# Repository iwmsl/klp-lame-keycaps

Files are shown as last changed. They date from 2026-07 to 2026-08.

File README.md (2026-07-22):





# KLP Lamé — Kailh Choc & MX Keycaps

Sculpted and curved keycaps for Kailh Choc and MX switches. Here is a project structure:

| Folder | Description |
| :--- | :--- |
| **Assets** | Various images and actual photos of keycaps |
| **Blender** | Blender files for preview image render |
| **Fusion 360** | Source files for [Autodesk Fusion 360](https://www.autodesk.com/products/fusion-360/overview) |
| **OpenSCAD** | Parametric [Angular](./OpenSCAD/README.md) remix — flat-sided, lower-profile variant |
| **Production** | Combined STL 3D models suitable for 3D-Printing services (like [JLC3DP](https://jlc3dp.com))  |
| **STEP** | 3D models in STEP format for any CAD or Slicer software |
| **STL** | 3D models in STL format for any CAD or Slicer software |

## Angular remix (OpenSCAD)

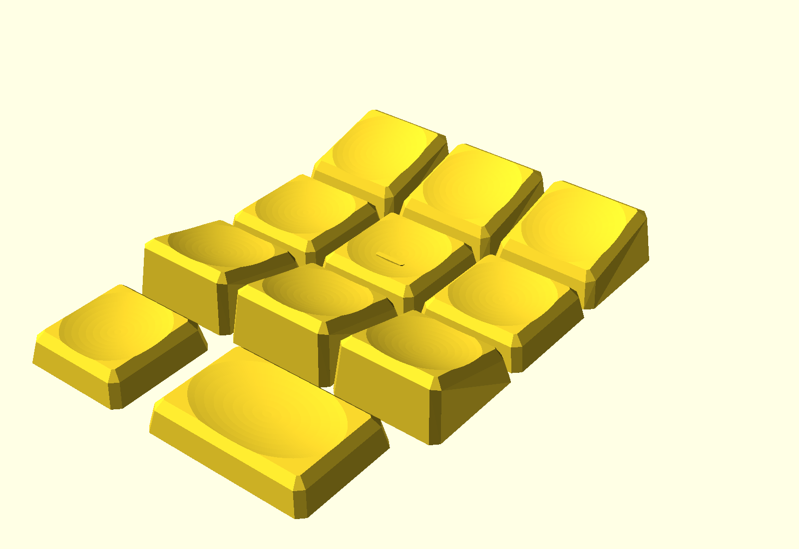
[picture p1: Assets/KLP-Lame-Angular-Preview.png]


There is also an angular, slightly lower-profile remix of the Lamé profile
with flat trapezoid sides, keeping the signature sloped & dished top. It is
fully parametric (OpenSCAD) and FDM-friendly (e.g. Bambu Lab A1 mini).
See [OpenSCAD/README.md](./OpenSCAD/README.md) for parameters, prebuilt STLs
and printing notes.

> `STEP` and `STL` folders contain all combinations of Choc/MX Stem + Choc/MX Size.
>
> There is also `90 deg Rotated` variants for Choc Stem.

There are currently 7 variants of 1U keycaps:
| Variant | Description |
| :--- | :--- |
| **Normal** | Just a flat keycap profile with a small recess, that is soothing for fingers |
| **Normal Tilted** | Same as Normal, but top profile has a 15° tilt and 0.5mm upward height compensation |
| **Normal Homing** | Has three little bumps that is useful to determine home positions |
| **Thumb** | Same as Normal, but top profile has a cut along down side |
| **Saddle** | Same as Thumb, but top profile has two symmetrical cuts |
| **Saddle Tilted** | Tilted version of Saddle. Same 15° and height compensation |
| **Saddle Homing** | Has three little bumps that is useful to determine home positions |

And also 5 variants of 1.5U keycaps:
| Variant | Description |
| :--- | :--- |
| **Normal** | Just a flat keycap profile with a small recess, that is soothing for fingers |
| **Thumb H**  | 1.5U variant of Thumb. Horizontal |
| **Thumb V**  | 1.5U variant of Thumb. Vertical (stem is rotated) |
| **Saddle H** | 1.5U variant of Saddle. Horizontal |
| **Saddle V** | 1.5U variant of Saddle. Vertical (stem is rotated) |

## What keycaps do I need for my keyboard?

First, you should choose Choc/MX stem (depends of your switches)<br>
Second, choose Choc/MX size that is suitable for your keyboard.<br>
Then, pick what keycap variants you want for your columns/rows/thumbs. It depends entirely of your choice.

For corne-like keyboards with 36-keys I use:

| Amount | Kind | Purpose |
| -----: | :--- | :--- |
| 20 | Saddle Tilted | For top and bottom rows |
| 16 | Saddle | For home row + 6 for thumbs |

or

| Amount | Kind | Purpose |
| -----: | :--- | :--- |
| 20 | Normal Tilted | For top and bottom rows |
| 10 | Normal | For home row |
| 6 | Thumb | For thumbs |

## How to print?

It is best to position the model more vertically to avoid tactile layer-to-layer bumps. Personally, I use 45° or 75° angle, but it's up to you.

`Production` folder contains files that you can use in any 3D-printing service like [JLC3DP](https://jlc3dp.com) or [PCBWay](https://www.pcbway.com/rapid-prototyping/3d-printing/). You can download them directly using links below:

### Normal

| File | Choc Stem + Choc Size | Choc Stem + MX Size | MX Stem + MX Size | MX Stem + Choc Size | Kinds |
| :--- | :--- | :--- | :--- | :--- | --- |
| Normal Part 1 | [Download][normal-part-1-choc] | [Download][normal-part-1-choc-mx] | [Download][normal-part-1-mx] | [Download][normal-part-1-mx-choc] | - 6 × Normal Tilted<br/>- 3 × Normal |
| Normal Part 2 | [Download][normal-part-2-choc] | [Download][normal-part-2-choc-mx] | [Download][normal-part-2-mx] | [Download][normal-part-2-mx-choc] | - 4 × Normal Tilted<br/>- 3 × Thumb<br/>- 1 × Normal Homing<br/>- 1 × Normal |
| Normal Part 3 | [Download][normal-part-3-choc] | [Download][normal-part-3-choc-mx] | [Download][normal-part-3-mx] | [Download][normal-part-3-mx-choc] | - 9 × Normal Tilted |

### Saddle

| File | Choc Stem + Choc Size | Choc Stem + MX Size | MX Stem + MX Size | MX Stem + Choc Size | Kinds |
| :--- | :--- | :--- | :--- | :--- | --- |
| Saddle Part 1 | [Download][saddle-part-1-choc] | [Download][saddle-part-1-choc-mx] | [Download][saddle-part-1-mx] | [Download][saddle-part-1-mx-choc] | - 6 × Saddle Tilted<br/>- 3 × Saddle |
| Saddle Part 2 | [Download][saddle-part-2-choc] | [Download][saddle-part-2-choc-mx] | [Download][saddle-part-2-mx] | [Download][saddle-part-2-mx-choc] | - 4 × Saddle Tilted<br/>- 4 × Saddle<br/>- 1 × Saddle Homing |
| Saddle Part 3 | [Download][saddle-part-3-choc] | [Download][saddle-part-3-choc-mx] | [Download][saddle-part-3-mx] | [Download][saddle-part-3-mx-choc] | - 9 × Saddle Tilted |

### Thumbs

| File | Choc Stem + Choc Size | Choc Stem + MX Size | MX Stem + MX Size | MX Stem + Choc Size | Kinds |
| :--- | :--- | :--- | :--- | :--- | --- |
| Thumbs | [Download][thumbs-part-1-choc] | [Download][thumbs-part-1-choc-mx] | [Download][thumbs-part-1-mx] | [Download][thumbs-part-1-mx-choc] | - 9 × Thumb |

[normal-part-1-choc]: ./Production/Choc%20Stem%20%2B%20Choc%20Size/Choc_Stem_Choc_Size_Normal_Part_1.zip
[normal-part-2-choc]: ./Production/Choc%20Stem%20%2B%20Choc%20Size/Choc_Stem_Choc_Size_Normal_Part_2.zip
[normal-part-3-choc]: ./Production/Choc%20Stem%20%2B%20Choc%20Size/Choc_Stem_Choc_Size_Normal_Part_3.zip

[normal-part-1-choc-mx]: ./Production/Choc%20Stem%20%2B%20MX%20Size/Choc_Stem_MX_Size_Normal_Part_1.zip
[normal-part-2-choc-mx]: ./Production/Choc%20Stem%20%2B%20MX%20Size/Choc_Stem_MX_Size_Normal_Part_2.zip
[normal-part-3-choc-mx]: ./Production/Choc%20Stem%20%2B%20MX%20Size/Choc_Stem_MX_Size_Normal_Part_3.zip

[normal-part-1-mx]: ./Production/MX%20Stem%20%2B%20MX%20Size/MX_Stem_MX_Size_Normal_Part_1.zip
[normal-part-2-mx]: ./Production/MX%20Stem%20%2B%20MX%20Size/MX_Stem_MX_Size_Normal_Part_2.zip
[normal-part-3-mx]: ./Production/MX%20Stem%20%2B%20MX%20Size/MX_Stem_MX_Size_Normal_Part_3.zip

[normal-part-1-mx-choc]: ./Production/MX%20Stem%20%2B%20Choc%20Size/MX_Stem_Choc_Size_Normal_Part_1.zip
[normal-part-2-mx-choc]: ./Production/MX%20Stem%20%2B%20Choc%20Size/MX_Stem_Choc_Size_Normal_Part_2.zip
[normal-part-3-mx-choc]: ./Production/MX%20Stem%20%2B%20Choc%20Size/MX_Stem_Choc_Size_Normal_Part_3.zip

[saddle-part-1-choc]: ./Production/Choc%20Stem%20%2B%20Choc%20Size/Choc_Stem_Choc_Size_Saddle_Part_1.zip
[saddle-part-2-choc]: ./Production/Choc%20Stem%20%2B%20Choc%20Size/Choc_Stem_Choc_Size_Saddle_Part_2.zip
[saddle-part-3-choc]: ./Production/Choc%20Stem%20%2B%20Choc%20Size/Choc_Stem_Choc_Size_Saddle_Part_3.zip

[saddle-part-1-choc-mx]: ./Production/Choc%20Stem%20%2B%20MX%20Size/Choc_Stem_MX_Size_Saddle_Part_1.zip
[saddle-part-2-choc-mx]: ./Production/Choc%20Stem%20%2B%20MX%20Size/Choc_Stem_MX_Size_Saddle_Part_2.zip
[saddle-part-3-choc-mx]: ./Production/Choc%20Stem%20%2B%20MX%20Size/Choc_Stem_MX_Size_Saddle_Part_3.zip

[saddle-part-1-mx]: ./Production/MX%20Stem%20%2B%20MX%20Size/MX_Stem_MX_Size_Saddle_Part_1.zip
[saddle-part-2-mx]: ./Production/MX%20Stem%20%2B%20MX%20Size/MX_Stem_MX_Size_Saddle_Part_2.zip
[saddle-part-3-mx]: ./Production/MX%20Stem%20%2B%20MX%20Size/MX_Stem_MX_Size_Saddle_Part_3.zip

[saddle-part-1-mx-choc]: ./Production/MX%20Stem%20%2B%20Choc%20Size/MX_Stem_Choc_Size_Saddle_Part_1.zip
[saddle-part-2-mx-choc]: ./Production/MX%20Stem%20%2B%20Choc%20Size/MX_Stem_Choc_Size_Saddle_Part_2.zip
[saddle-part-3-mx-choc]: ./Production/MX%20Stem%20%2B%20Choc%20Size/MX_Stem_Choc_Size_Saddle_Part_3.zip

[thumbs-part-1-choc]: ./Production/Choc%20Stem%20%2B%20Choc%20Size/Choc_Stem_Choc_Size_Thumbs.zip
[thumbs-part-1-choc-mx]: ./Production/Choc%20Stem%20%2B%20MX%20Size/Choc_Stem_MX_Size_Thumbs.zip
[thumbs-part-1-mx]: ./Production/MX%20Stem%20%2B%20MX%20Size/MX_Stem_MX_Size_Thumbs.zip
[thumbs-part-1-mx-choc]: ./Production/MX%20Stem%20%2B%20Choc%20Size/MX_Stem_Choc_Size_Thumbs.zip

## Can I use these models for a production and sale?

Yes. But you must leave a mention of this repository/author to end users.

## Can I modify, fork, post (or whatever) these models?

Yes. Rules are the same. Give a credit to the author.

## Changelog
v1.5u
- [Models] Well, 1.5U keycap sizes for both Choc/MX Stem + Choc/MX Size.

v1.4
- [Models] Updated Choc Stem to be compatible with silent choc switches.
- [Project] Added Choc_Stem + MX_Size 90° rotated variants (both STL and STEP).
- [Production] Increased surface area of connected parts to improve print stability.

v1.3
- [Models] Added mix and match variants for Choc/MX Stem + Choc/MX Size.
- [Project] Updated folder structure to accomodate mix and match variants.
- [Project] Removed Lychee (legacy) project files.

v1.2
- [Models] Added Choc version with 90° rotated stem.

v1.1

- [Models] Added chamfers along inner bottom line (1.2mm for Choc and 1.4mm for MX).
- [Project] Added separate Fusion project files.
- [Project] Updated Images & Photos.

> Now the models are also suitable for FDM 3D Printers. But I still recommend using SLA for better quality.

v1.0

- Initial Release.

## Images & Photos

### From various awesome people


By [u/unspecified-work](https://www.reddit.com/user/unspecified-work/) from [Reddit](https://www.reddit.com/r/ErgoMechKeyboards/comments/1oznwnv/splayed_sweep/)


By [u/socopopes](https://www.reddit.com/user/socopopes/) from [Reddit](https://www.reddit.com/r/ErgoMechKeyboards/comments/1dx9d7j/down_14_more_keys_only_34_more_to_go/)


By [u/bert_plasschaert](https://www.reddit.com/user/bert_plasschaert/) from [Reddit](https://www.reddit.com/r/ErgoMechKeyboards/comments/1dmirsg/totem_tenting_bottom_plate/)


By [proostas](https://t.me/proostas) from [Ergonaut Keyboards Ru](https://t.me/ergonautkb_ru)

### Original photos



> The keyboard is my side-project [Lapka](https://github.com/braindefender/lapka)




> The keyboard is [Cantor Remix](https://github.com/nilokr/cantor-remix)

## Contacts

@braindefender (preferably, [Telegram](t.me/braindefender), but also [GMail](mailto:braindefender@gmail.com) and [Reddit](https://www.reddit.com/user/braindefender/))

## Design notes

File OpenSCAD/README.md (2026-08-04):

# KLP Lamé Angular (OpenSCAD)



KLP Lamé の特徴である「中央がくぼみ四辺が持ち上がる皿状の天面(前後のロールオフ)」を
保ちつつ、側面を**フラットで角のはっきりした台形**にした **角ばった・低背リミックス** です。
天面は元と同じ球面ディッシュ、側面はフラット、稜線だけを軽く丸めた「ラウンデッドボックス」構成。
OpenSCAD 製のフルパラメトリックモデルなので、寸法・形状を自由に調整できます。

An angular, lower-profile remix of KLP Lamé. Flat, crisp trapezoid
sides (a "rounded box" with only the perimeter edges softened) carry
the same spherical dish as the original — concave scoop rising toward
all four edges, rolling off over the front/back walls. Fully parametric
OpenSCAD source. Stem and cavity dimensions are measured from the
original STLs, so switch fit is identical to the originals.

## 特徴 / Features

- **角ばった形状** — 側面はフラット、稜線のみ軽い丸め
- **詰めた間隔** — 19.05mm ピッチ向けに底面 18.5×18.5mm。
  キー間はリムで 0.55mm、天面どうしで 2.05mm
- **皿状の天面は維持** — 元と同じ球面ディッシュ(中央がくぼみ四辺へ持ち上がる)。
  Tilted は 15° 傾斜。前端をホーム段と同じ高さにして段差なくつなげています
- **低背化** — クラウン高さ 5.0 mm(オリジナル約 5.6 mm より低い)、
  指の当たる谷底は約 3.9 mm
- **互換ステム** — Choc(2本足 1.15×2.95、間隔5.7)/ MX(Ø5.5 ボス+十字)
  はオリジナル実測値そのまま
- **サポート不要で印刷できる形状** — 外殻に 45° を超える面がありません
  (下記「オーバーハング」)

## バリアント / Variants

4 種 × ステム(Choc/MX) × サイズ(Choc 17.5×16.5 / MX 18×18 / MX Tight 18.5×18.5):

| Variant | 説明 |
| :--- | :--- |
| Normal | 皿状のくぼみを持つ基本形 |
| Normal Homing | Normal+ホーミングバー |
| Normal Tilted | 15° 傾斜(上下段用) |
| 1.5U Normal | Normal の 1.5U 幅版(親指用) |

ビルド済み STL は `STL/` 以下(`build.sh` で再生成できます)。
ホーミングは `homing = "dots"` でオリジナル風の3点バンプにも変更可能です。

## サイズ / Footprint sizes

| `size_type` | 底面 | 想定ピッチ | リムの隙間 |
| :--- | :--- | :--- | :--- |
| choc | 17.5 × 16.5 | 18 / 17 mm | 0.5 mm |
| mx | 18 × 18 | 19 mm | 1.0 mm |
| **mx_tight**(c4mtb 用) | **18.5 × 18.5** | **19.05 mm** | **0.55 mm** |

`mx_tight` は Corne v4 Mini 実測の 19.05mm ピッチに合わせた詰めた版です。
底面を 0.5mm 広げただけで側面の傾きは変えていないので、天面も 16.5 → 17.0mm
に広がり、天面どうしの隙間が 2.5 → 2.05mm に詰まります。

## 側面スタイル / Sidewall styles

キー間の隙間をどれだけ詰めるかを `side_style` で選べます(`mx_tight` の場合):

| スタイル | 側面 | 天面 | 天面どうしの隙間 |
| :--- | :--- | :--- | :--- |
| **chiclet**(既定) | ほぼ垂直(約11°) | 17.0×17.0 | 2.05 mm |
| wide | 従来のテーパー(約27°) | 14.5×14.5 | 4.55 mm |
| skirt | 下1.5mmは垂直、その上テーパー | 15.5×15.5 | リム0.55 / 上3.55 mm |

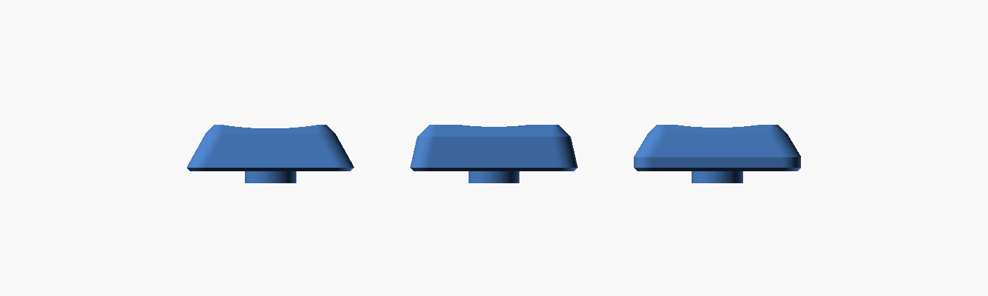
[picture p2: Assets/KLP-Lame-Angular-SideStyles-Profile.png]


## 傾斜 / Tilt

Tilted は前端の footprint 辺を軸に 15° 起こします。回転軸の高さが
`tilt_front_height` = `crown_height` なので、**前端はホーム段のクラウンと同じ 5.0mm**、
そこから後方へ向かって持ち上がり、後端のクラウンはリムから 9.3mm になります。

上段はそのまま、下段は 180° 回して置くと、3段が一つの浅いボウルになります。
`tilt_angle` を上げるぶんだけ後端が `cap_d × sin(tilt)` 高くなるので、
高さを抑えたいときは `tilt_front_height` を下げてください
(ただしホーム段との間に段差ができます)。

## Corne v4 Mini 印刷セット / Print set

[c4mtb](https://github.com/iwmsl/c4mtb)(Corne v4 Mini 相当)向けの
**両手36キー一式**を、Bambu Lab A1 mini(180×180mm)にそのまま並べた
プレートを用意しています(`MX Stem + MX Tight Size`)。詳細は
[Plates/README.md](./Plates/README.md)。

| ファイル | 向き | 特徴 |
| :--- | :--- | :--- |
| **`Plates/Plate_A1mini_Corne36_Tipped.stl`**(推奨) | **上向きから48°傾ける** | **36キー一括・サポート不要。外殻に45°超の面なし(最大42°)。天面の積層痕も出ません** |
| `Plates/Plate_A1mini_Corne36_BottomDown.stl` | 上向き(底面を下) | サポート必須(リム下と空洞内)。天面に同心円状の積層痕が出ます |
| `Plates/Plate_A1mini_Test_OneEach_RearSideDown.stl` | 側面を下 | 全4種を各1個。8mmブリム推奨 |

36キー版の内訳: Normal Tilted×20 / Normal×12(ホーム段8＋1U親指4) /
Normal Homing×2 / 1.5U Normal×2 = 36。

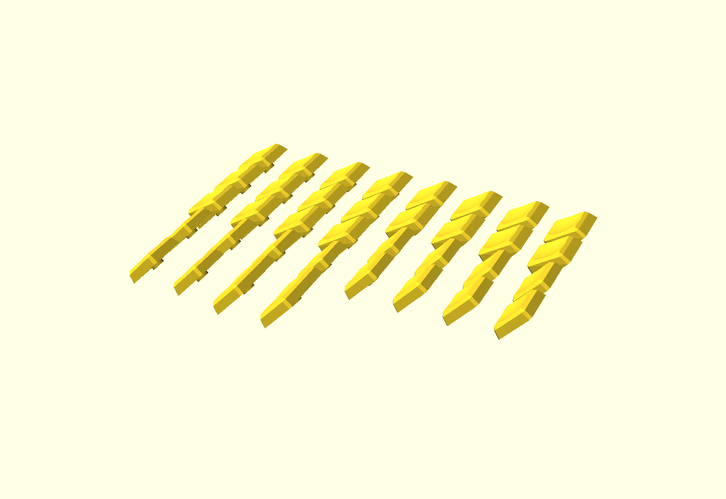
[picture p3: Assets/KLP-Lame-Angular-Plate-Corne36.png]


## オーバーハング / Overhang

`overhang.py` が組み上がった STL を読み、指定の向きに傾けて
「45° を超える面がどこに何 mm² あるか」を出します。キャップは
**外殻**(壁・リム下面・天面。ここが崩れると印刷が失敗する)と
**内側**(空洞・天井・ステム。スイッチに隠れ、崩れても効くのは嵌合だけ)
に分けて集計します。

```sh
python3 overhang.py --tip=48 "STL/MX Stem + MX Tight Size/"*.stl
python3 overhang.py --sweep "STL/MX Stem + MX Tight Size/MX_Stem_MX_Tight_Size_Angular_Normal.stl"
```

傾ける角度は、キャップの**水平面**(リム下面と空洞の天井、合わせて約340mm²)と
**垂直面**(十字穴の側壁)を天秤にかけます。前者は「90° − 傾き」、後者は「傾き」に
なり、和が常に 90° なので、どちらか一方は必ず 45° 以上になります。
面積の大きい外側に余裕を持たせるのが正解で、48° がその最良点です。

| 傾き | 外殻の最大角 | 外殻の45°超 | 内側の45°超 |
| --: | --: | --: | --: |
| 45° | 45.0° | 65.9 mm² | 157.1 mm² |
| 46° | 44.0° | 0.0 mm² | 15.1 mm² |
| **48°** | **42.0°** | **0.0 mm²** | **15.9 mm²** |
| 50° | 43.0° | 0.0 mm² | 17.2 mm² |
| 52° | 45.0° | 130.3 mm² | 20.3 mm² |

残る 15.9mm² は Ø5.5 ボスの中に彫られた幅 1.2mm の十字穴の側壁で、
スイッチに隠れるうえ左右の壁がすぐ繋がるブリッジです。

この形になるまでに直した点:

- **空洞を外向きテーパーに** — 空洞が上へ行くほど狭まっていた頃、その壁は
  32mm² にわたって 80° という、モデル中で断然最悪の面でした。逆向きに
  テーパーを付けて壁を空洞から離す向きに倒すと、そのまま自立面になります。
  スイッチ側は上へ行くほど細くなるので、嵌合には影響しません。
  リムの壁が厚い `mx_tight` だけがこのテーパーを取れる余裕を持っており、
  choc / mx サイズは壁厚を優先して垂直な空洞になります(45°超は残りますが、
  かつての 80° ではなく傾き角そのもの＝48°です)
- **ステム入口のテーパーをザグリに** — 円錐状の面取りは四方すべてが
  空洞側に倒れ込むので、傾けると 80° に達していました。段差にしても
  面取り済みの MX ステムなら問題なく入ります
- **ボスをテーパーに** — リムより上は switch に入らないので自由に倒せます
- **リムの継ぎ目を除去** — `bottom_edge_round = 0` のとき hull の底が二重に
  なり、0.01mm だけ完全垂直な帯が残っていました

## 使い方 / Usage

### OpenSCAD GUI(カスタマイザ)

`klp-lame-angular.scad` を開いて Customizer からパラメータを変更し、
F6 → STL エクスポート。主なパラメータ:

| パラメータ | 既定値 | 説明 |
| :--- | :--- | :--- |
| `stem_type` | choc | choc / mx |
| `size_type` | choc | choc / mx / mx_tight(上表参照) |
| `variant` | normal | normal / tilted |
| `homing` | none | none / bar / dots |
| `crown_height` | 5.0 | クラウン(天面の外周稜線)の高さ ※ |
| `dish_depth` | 1.15 | 中央のくぼみ深さ。谷底 = `crown_height` − `dish_depth` |
| `dish_radius` | 28 | 球面ディッシュのR(小さいほど深く丸い皿) |
| `side_style` | chiclet | chiclet / wide / skirt(上表参照) |
| `corner_radius` | 1.9 | 底面の角R(小さいほど角ばる) |
| `cavity_flare` / `wall_min` | 0.25 / 0.6 | 空洞を上へ向けて片側 `cavity_flare` だけ広げる(印刷時に自立させるため)。ただし天井での壁厚が `wall_min` を下回らない範囲まで。リムの壁厚はサイズごとに自動(mx_tight 1.25 / その他 1.0mm)で、空洞の口はオリジナルと同寸です |
| `tilt_angle` / `tilt_front_height` | 15 / 5.0 | Tilted の傾斜角と前端高さ。前端＝`crown_height` でホーム段と段差なし |

※ 谷底(`crown_height` − `dish_depth`)− 空洞深さ(約2.0)が天板の最小厚です。
既定値で約 1.85 mm。FDM なら 1.0 mm 以上を推奨します。

### CLI

```sh
# 単品
openscad -o cap.stl -D 'stem_type="mx"' -D 'size_type="mx_tight"' -D 'variant="tilted"' klp-lame-angular.scad

# 全24種 + プレート + オーバーハング検査 + プレビュー画像
./build.sh
```

## Bambu Lab A1 mini での印刷 / Printing

**上向きから48°傾けて、サポートなしで印刷するのを推奨します。**

- ノズル: 0.4 mm / レイヤー: 0.08–0.12 mm
- 壁: 4 以上、インフィル: 100%(小さい部品なのでほぼ変わりません)
- 向き: 48°傾け(推奨)。**サポート不要**。ブリムは3mm程度
- 試作プレート: 接地面が小さいため8mmブリム推奨
- 材料: PLA / PETG(テクスチャPEIプレート)
- シーム: 後方に寄せる(Seam position: Rear)
- はめ合いがきつい/ゆるい場合: Bambu Studio の
  「X-Y hole compensation」を ±0.05 mm 程度調整するか、
  scad の `choc_leg_w` / `mx_slot_v` などを直接調整

レジン印刷でも問題ありません。

## クレジット / Credit

Original KLP Lamé by [braindefender](https://github.com/braindefender/KLP-Lame-Keycaps).
This remix follows the same license — keep the credit to the original author.

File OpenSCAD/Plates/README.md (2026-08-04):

# Print plates — KLP Lamé Angular (Bambu Lab A1 mini)

Ready-to-slice plates for the angular remix, pre-arranged to fit the
A1 mini's 180 × 180 mm bed. Start with the four-cap trial plate, then
print the whole set with `Plate_A1mini_Corne36_Tipped.stl`.

Caps used: **MX Stem + MX Tight Size** (18.5 × 18.5 mm footprint,
chiclet sidewalls, for the 19.05 mm pitch — 0.55 mm between caps at the
rim, 2.05 mm between their top faces).

## Corne set — `Plate_A1mini_Corne36_Tipped.stl` (recommended, support-free)

The 36 caps **tipped 48° from upright**, printed with **no support**.

Tipping plays the cap's horizontal faces off against its vertical ones.
The rim underside and the cavity ceiling — about 340 mm² between them —
end up at 90° minus the tip angle; the cross recess inside the stem boss
ends up at the tip angle itself. The two always sum to 90°, so one of
them is at 45° or worse whatever angle is picked, and the margin belongs
to the large exposed faces rather than a 1.2 mm slot buried in the boss.
That leaves a window between two cliffs, and the visible shell is
flattest across the middle of it:

| Tip | Outer worst | Outer over 45° | Inner over 45° | |
| --: | ---: | ---: | ---: | :-- |
| 45° | 45.0° |  65.9 mm² | 157.1 mm² | horizontals go over |
| 46° | 44.0° | 0.0 mm² |  15.1 mm² | |
| **48°** | **42.0°** | **0.0 mm²** | **15.9 mm²** | |
| 50° | 43.0° | 0.0 mm² |  17.2 mm² | |
| 52° | 45.0° | 130.3 mm² |  20.3 mm² | tilted rear wall goes over |

Nothing on the outside of any cap in the set — 1U, 1.5U, tilted or not —
passes **42°** at 48°, so the plate prints with no support at all and
with three degrees in hand at both ends of the window. The upper cliff
is the tilted cap: its rear wall stands only 7° off vertical, against
11.5° on a flat cap, because the tilt raises the crown without moving
the rim.

- Size: approximately **164.2 × 114.0 × 16.0 mm** — fits the bed
- **Supports off.** Use a **3 mm brim**: the caps balance on an edge,
  and at 3 mm apart a wider brim fuses all 36 into one sheet
- The layers cross the dish steeply, so the touch surface comes out free
  of the concentric terraces an upright print leaves
- What is *not* solved: 15.9 mm² inside the stem boss, the walls of the
  1.2 mm cross recess, sitting at exactly the tip angle. It is hidden
  inside the switch and bridges to its own opposite wall, but the socket
  may droop enough to tighten the fit. Trim it with X-Y hole
  compensation if so.
- Re-check any change with `python3 overhang.py --tip=48 "../STL/MX Stem
  + MX Tight Size/"*.stl`, or `--sweep` for the table above. Set
  `TIP_ANGLE_DEG` in `make_plate.py` to try another angle.

This depends on `bottom_edge_round = 0` in the .scad. That 45° chamfer
existed only to relieve elephant foot on a bottom-down print, and
tipped ~45° it becomes a dead-horizontal shelf on the outside of the
cap — the single worst overhang on the whole model.

## Corne set — `Plate_A1mini_Corne36_BottomDown.stl` (needs support)

All 36 caps **upright**, bottom/stem toward the bed. The alternative if
edge-balanced caps are a problem on your machine: an upright cap tapers
inward as it rises, so nothing above the first 3 mm can curl into the
nozzle at all.

- Size: approximately **152.1 × 169.0 × 10.6 mm** — fits the bed
- The cap rests on the Ø5.5 stem boss with the rim 1.3 mm clear, so it
  **needs support** under the rim and inside the cavity, plus a brim
- Cost: the dish prints as stacked layers, leaving faint concentric
  terraces on the touch surface. At 0.08 mm layers the steps are
  ~0.27 mm wide at the dish edge and wider toward the centre.

## Trial plate — all variants

`Plate_A1mini_Test_OneEach_RearSideDown.stl` contains one of every
variant (four caps total), each laid on its **rear outer side face** —
the upper side in the model's top view. Inner cavity walls and tiny
rounded/chamfer faces are excluded, so the choice is a real supporting
face rather than an unstable edge or point. After the contact face is
chosen, every cap is rotated only within the build-plate plane so all
stem axes point the same way. This final rotation does not change
contact area or stability.

- Size: approximately **32.4 × 49.5 × 18.4 mm**
- Actual contact area per cap: **58.8–130.6 mm²**
- Layout, viewed from above:

| Row | Left | Middle | Right |
| :-- | :--- | :----- | :---- |
| 1 | Normal | Normal Homing | Normal Tilted |
| 2 | 1.5U Normal | | |

Use tree supports and an **8 mm brim** for the first print.

## Quality-tuned Bambu project — PLA

`KLP_Lame_4Cap_A1mini_PLA_Quality.3mf` packages the same four trial caps
as separately selectable objects and embeds a conservative A1 mini /
0.4 mm nozzle / PLA process configuration. The matching importable
process preset is `KLP_Lame_A1mini_PLA_Quality_Process.json`.

The embedded profile uses 0.12 mm layers, slower first-layer and wall
speeds, an 8 mm outer brim, and dense Normal/Snug support interfaces. It
is intended to diagnose and improve the rough support-facing surfaces
near the build plate. This profile prioritizes underside quality rather
than minimum support material. For a support-minimized print, disable
automatic supports and paint Tree supports only beneath the stem boss
and the first floating edges.

## Full 36-key Corne set

| Bill of materials | Qty |
| :--- | --: |
| Normal Tilted (top & bottom rows) | 20 |
| Normal (home row 8 + 1U thumbs 4) | 12 |
| Normal Homing (index home keys) | 2 |
| 1.5U Normal (one thumb per hand) | 2 |
| **Total** | **36** |

## Slicing (Bambu Studio, A1 mini)

- Nozzle 0.4 mm, layer height 0.08–0.12 mm, walls ≥ 4, infill 100 %.
- **Supports: off** for the Tipped plate — that is the point of 48°.
  BottomDown does need support, under the rim and inside the cavity.
- Material: PLA or PETG.
- Brim: **3 mm** on the Tipped plate (caps are only 3 mm apart, so a
  wider brim fuses them all into one sheet and is a chore to remove).
  8 mm is fine on the four-cap trial plate, where there is room.
- If the switch fit is tight/loose, tune Bambu Studio's *X-Y hole
  compensation* by ±0.05 mm, or edit the stem params in the `.scad`.

## Regenerating

Plates are generated from the built STLs:

```sh
./build.sh                          # build caps, every plate and the overhang check
python3 make_plate.py Plates test   # trial plate only
python3 make_plate.py Plates full   # the two full-set plates
python3 make_plate.py Plates        # all of them
```

Edit `BOM` in `make_plate.py` to change counts. Edit `TEST_VARIANTS` to
change the trial set.

Regenerate the quality-tuned 3MF and its standalone preset from the
repository root:

```sh
python3 OpenSCAD/make_quality_3mf.py \
  --repo-root . \
  --output OpenSCAD/Plates/KLP_Lame_4Cap_A1mini_PLA_Quality.3mf \
  --preset-output OpenSCAD/Plates/KLP_Lame_A1mini_PLA_Quality_Process.json
```

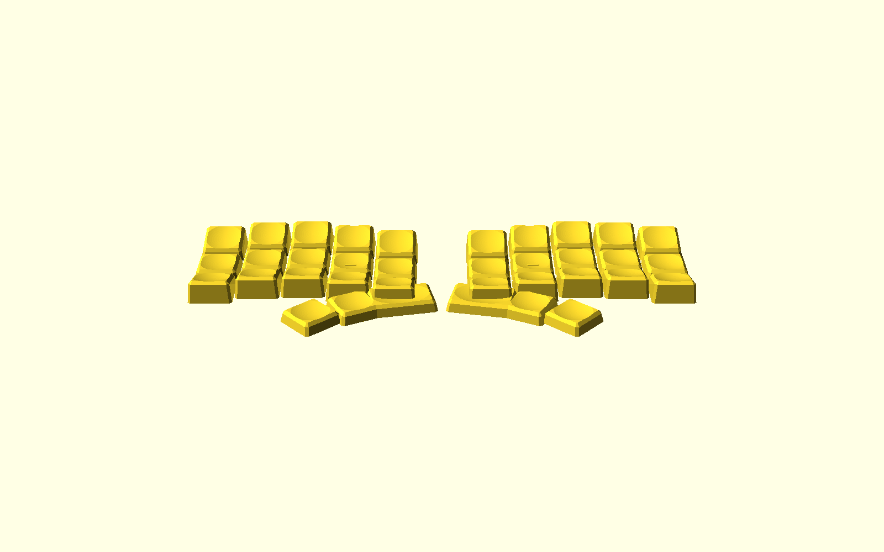
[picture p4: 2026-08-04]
Assets/KLP-Lame-Angular-Corne-Layout.png

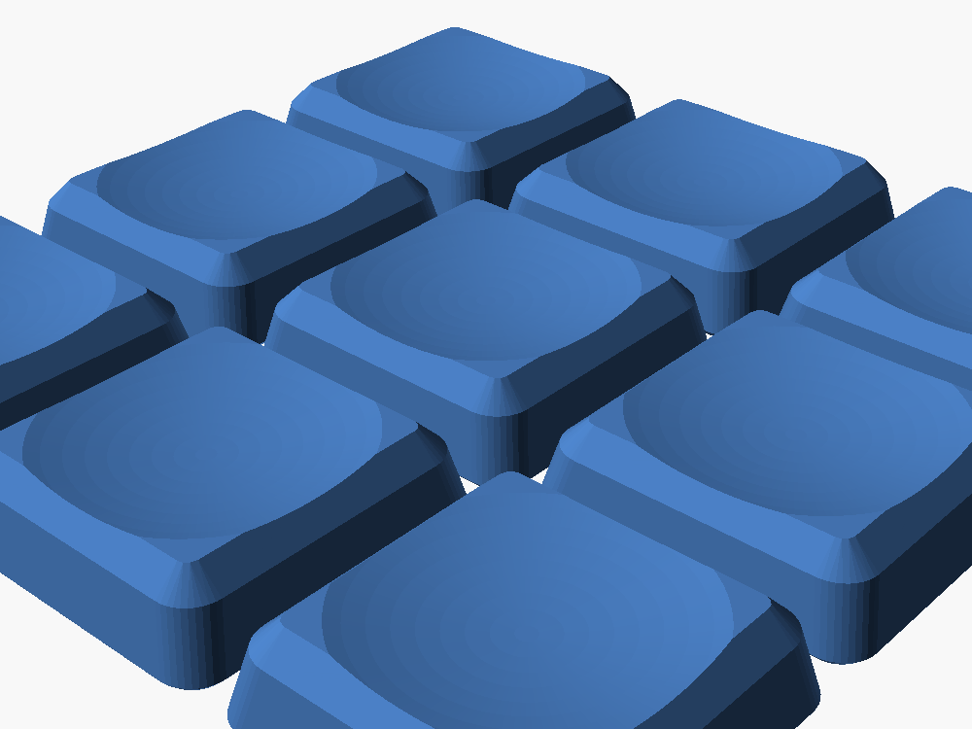
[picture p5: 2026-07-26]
Assets/KLP-Lame-Angular-SideStyles-Grid-Chiclet.png

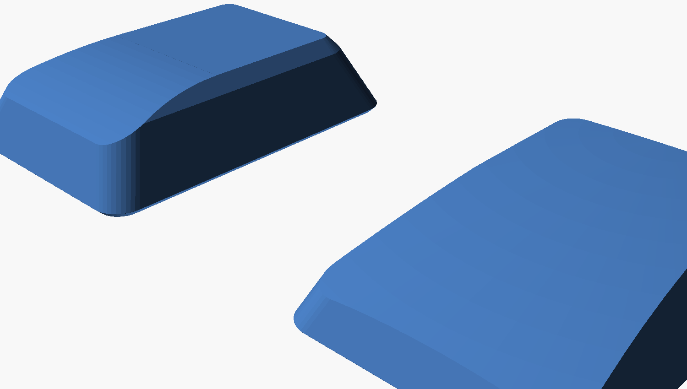
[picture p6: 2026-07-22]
Assets/KLP-Lame-Angular-Thumb15.png

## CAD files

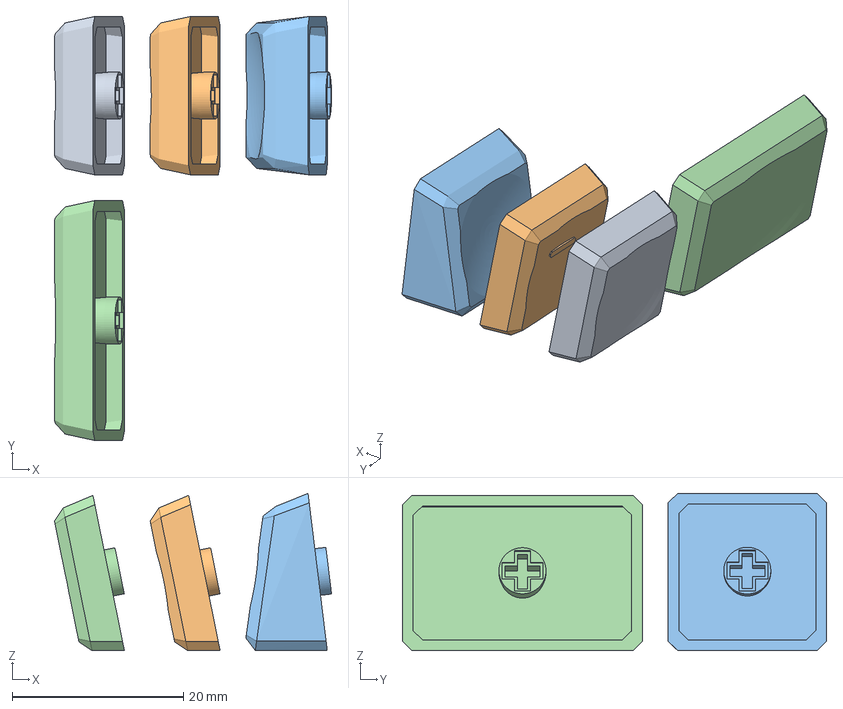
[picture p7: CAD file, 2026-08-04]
OpenSCAD/Plates/KLP_Lame_4Cap_A1mini_PLA_Quality.3mf
32.4 x 49.5 x 18.4 mm
Normal
Normal Homing
Normal Tilted
1.5U Normal

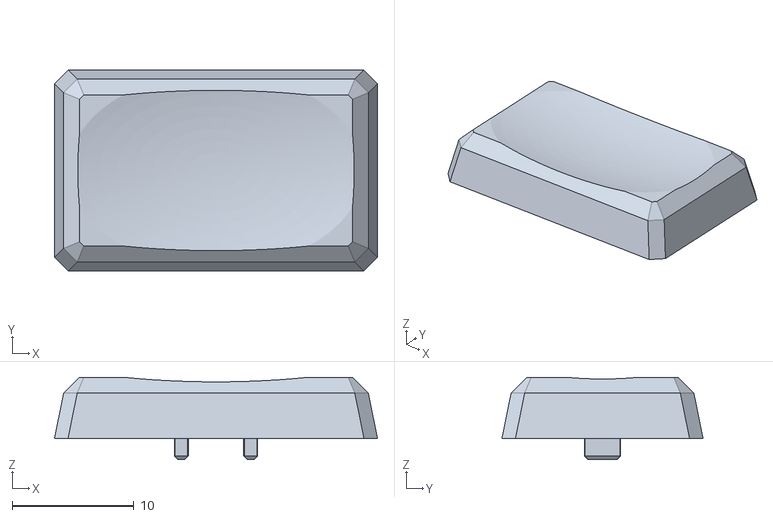
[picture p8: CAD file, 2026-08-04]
OpenSCAD/STL/Choc Stem + Choc Size/Choc_Stem_Choc_Size_Angular_1.5U_Normal.stl
26.5 x 16.5 x 6.76

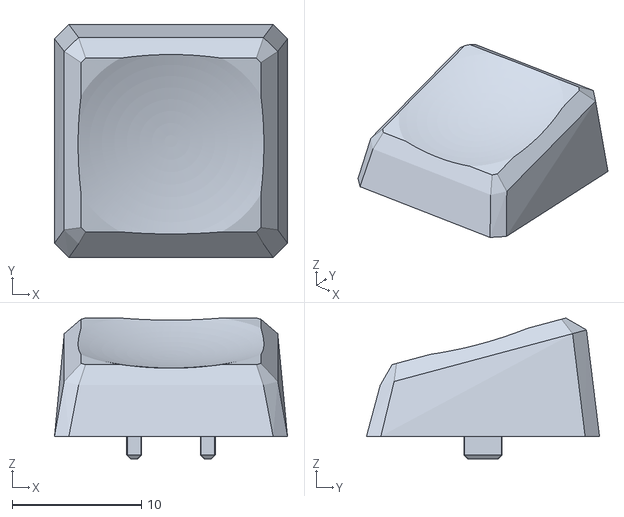
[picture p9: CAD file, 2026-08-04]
OpenSCAD/STL/Choc Stem + MX Size/Choc_Stem_MX_Size_Angular_Normal_Tilted.stl
18.0 x 18.0 x 10.9

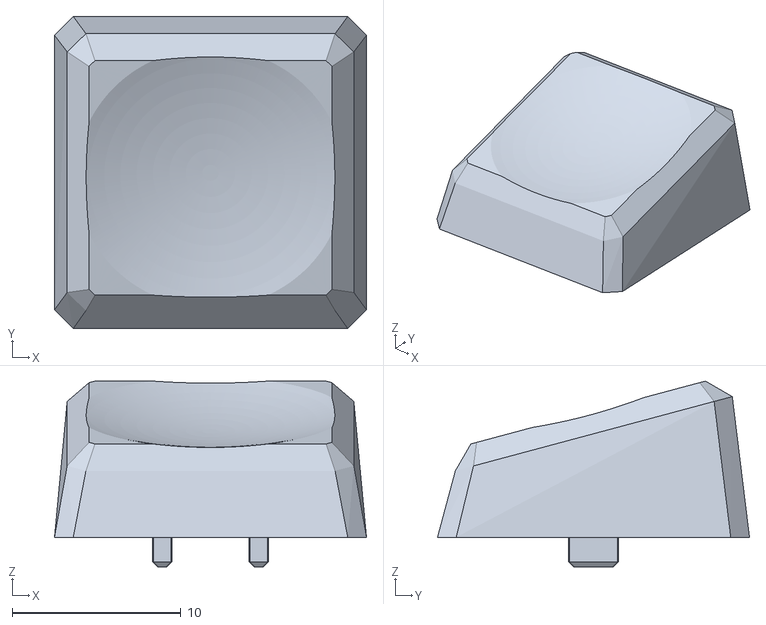
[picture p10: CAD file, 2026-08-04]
OpenSCAD/STL/Choc Stem + MX Tight Size/Choc_Stem_MX_Tight_Size_Angular_Normal_Tilted.stl
18.5 x 18.5 x 11.0

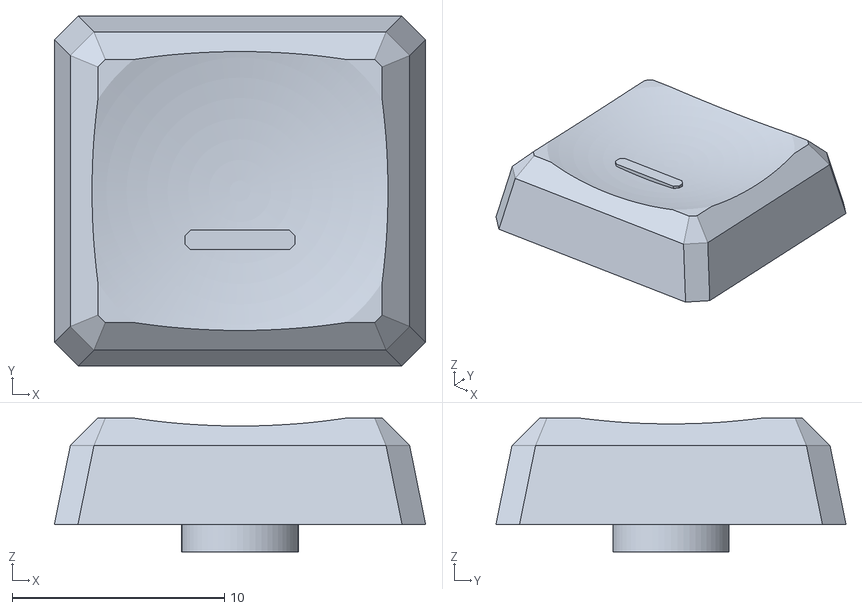
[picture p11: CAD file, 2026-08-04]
OpenSCAD/STL/MX Stem + Choc Size/MX_Stem_Choc_Size_Angular_Normal_Homing.stl
17.5 x 16.5 x 6.31

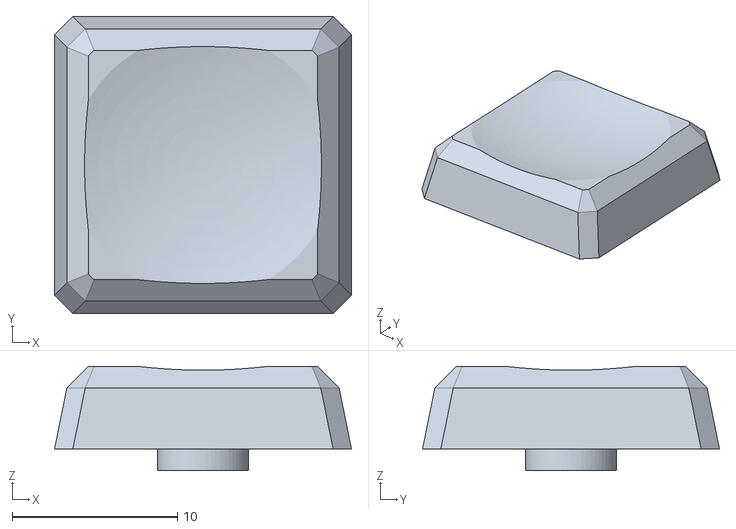
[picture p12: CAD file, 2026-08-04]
OpenSCAD/STL/MX Stem + MX Size/MX_Stem_MX_Size_Angular_Normal.stl
18.0 x 18.0 x 6.31

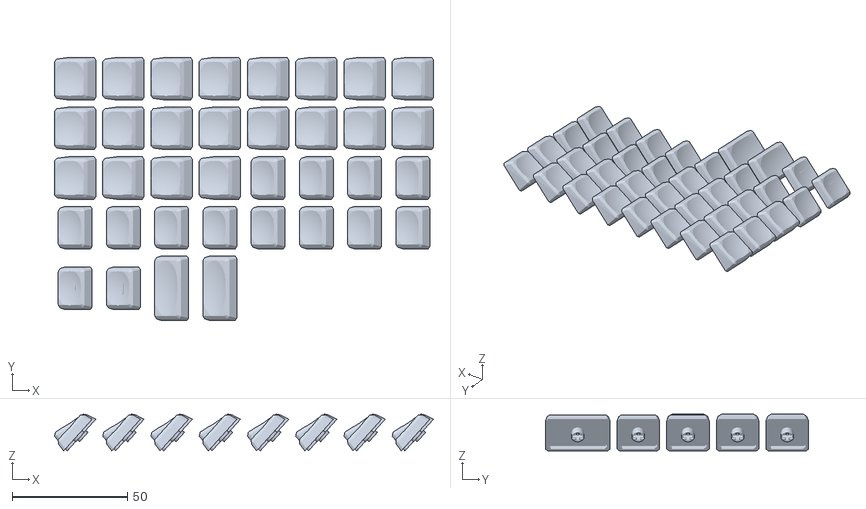
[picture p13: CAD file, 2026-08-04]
OpenSCAD/Plates/Plate_A1mini_Corne36_Tipped.stl
164.2 x 114.0 x 16.0

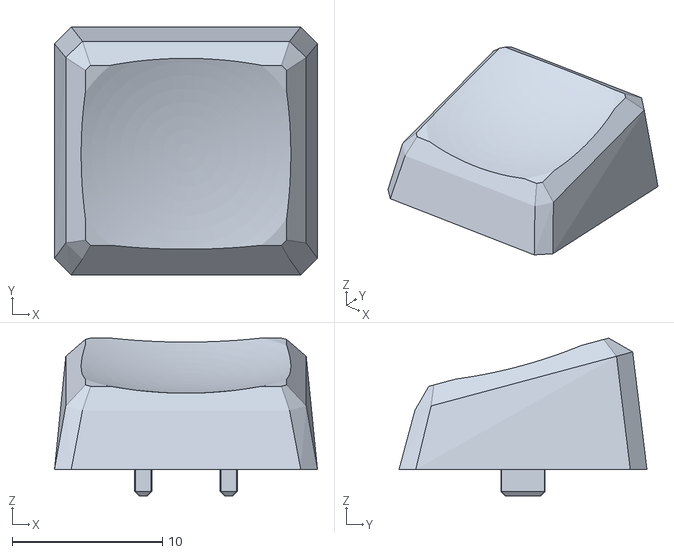
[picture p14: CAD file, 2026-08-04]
OpenSCAD/STL/Choc Stem + Choc Size/Choc_Stem_Choc_Size_Angular_Normal_Tilted.stl
17.5 x 16.5 x 10.5

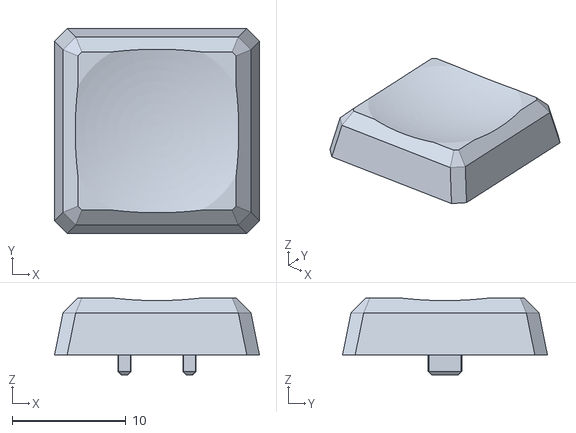
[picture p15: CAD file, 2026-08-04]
OpenSCAD/STL/Choc Stem + MX Size/Choc_Stem_MX_Size_Angular_Normal.stl
18.0 x 18.0 x 6.76

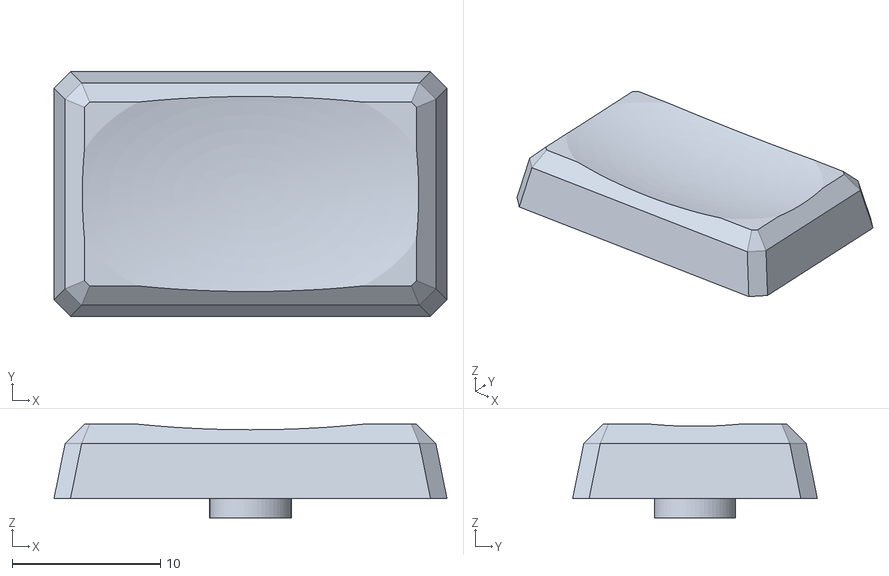
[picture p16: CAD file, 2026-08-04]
OpenSCAD/STL/MX Stem + Choc Size/MX_Stem_Choc_Size_Angular_1.5U_Normal.stl
26.5 x 16.5 x 6.31

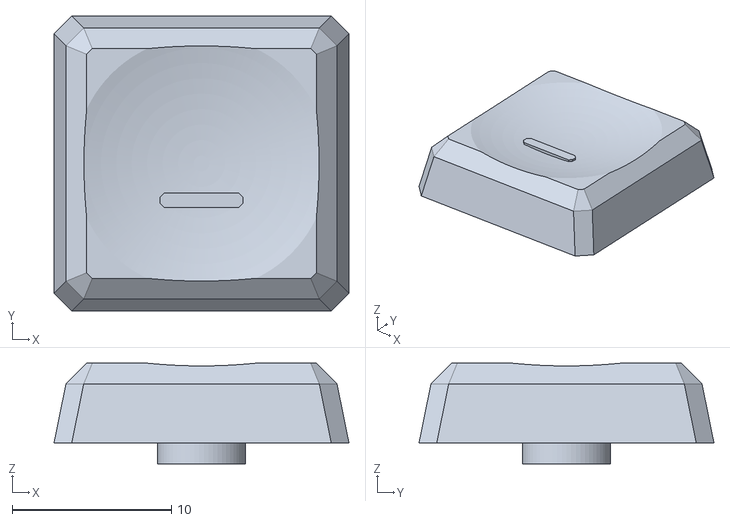
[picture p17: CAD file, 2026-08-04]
OpenSCAD/STL/MX Stem + MX Tight Size/MX_Stem_MX_Tight_Size_Angular_Normal_Homing.stl
18.5 x 18.5 x 6.31

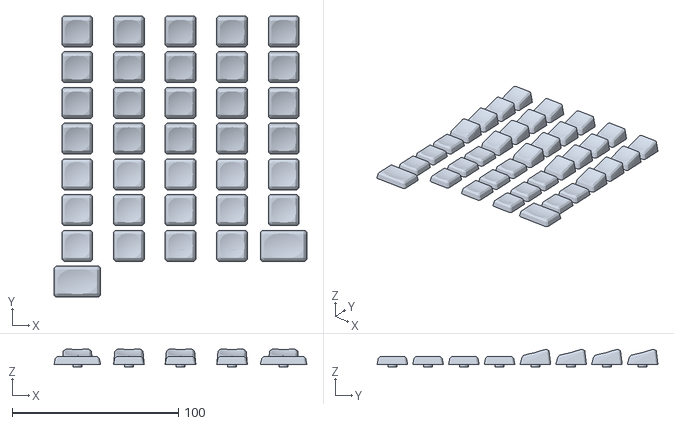
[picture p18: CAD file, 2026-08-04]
OpenSCAD/Plates/Plate_A1mini_Corne36_BottomDown.stl
152.1 x 169.0 x 10.6

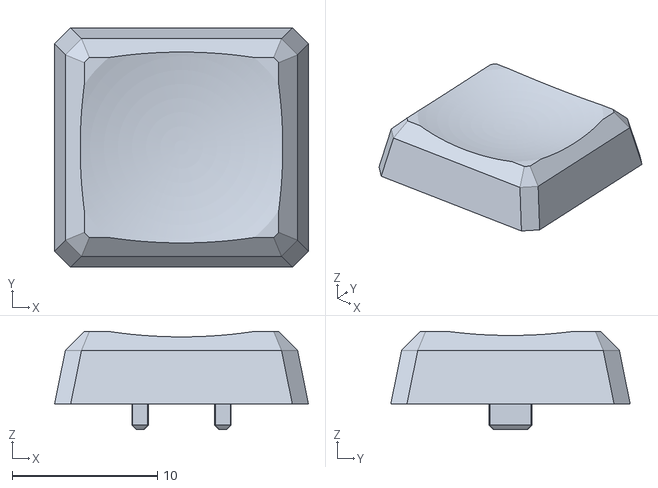
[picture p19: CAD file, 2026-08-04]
OpenSCAD/STL/Choc Stem + Choc Size/Choc_Stem_Choc_Size_Angular_Normal.stl
17.5 x 16.5 x 6.76

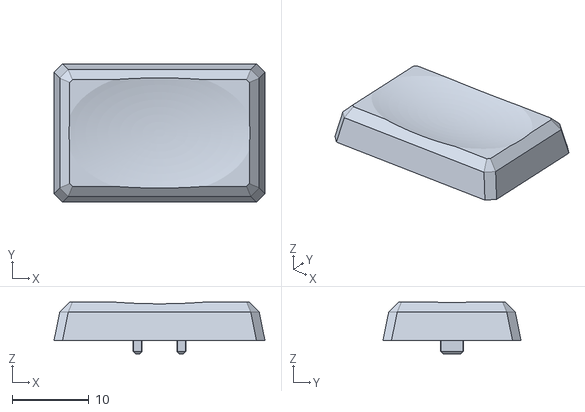
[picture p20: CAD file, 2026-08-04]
OpenSCAD/STL/Choc Stem + MX Size/Choc_Stem_MX_Size_Angular_1.5U_Normal.stl
27.5 x 18.0 x 6.76

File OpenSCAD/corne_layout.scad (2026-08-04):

// Corne v4 Mini (3x5+3 split) — keycap arrangement preview.
// Keycaps only, laid out roughly as they'd sit on the board: a sketch
// for judging how the caps read together, not the board's placement
// data. Requires the MX Stem + MX Tight Size STLs (run build.sh first).

dir    = "STL/MX Stem + MX Tight Size/";
prefix = "MX_Stem_MX_Tight_Size_Angular_";

pitch = 19.05; // c4mtb key spacing, both axes
gap   = 40;    // between the two halves (inner column to inner column)

// Columns from inner-index (0, nearest center) out to pinky (4).
// Downward stagger of each column (mm), classic Corne finger stagger.
stagger = [9, 4, 0, 1, 5];

module cap(name) import(str(dir, prefix, name, ".stl"));

// One hand: inner-index column at local x = 0, columns march left,
// thumb cluster fanning below toward the center.
module hand() {
    for (j = [0 : 4]) {
        x = -j * pitch;
        s = stagger[j];
        // top & bottom rows: tilted, the bottom one turned around so
        // both rake away from the home row
        translate([x, pitch - s, 0]) cap("Normal_Tilted");
        translate([x, -pitch - s, 0]) rotate([0, 0, 180]) cap("Normal_Tilted");
        // home row: normal, homing bump on the index home key
        translate([x, -s, 0]) cap(j == 1 ? "Normal_Homing" : "Normal");
    }
    // thumb cluster: 1.5U innermost, then two 1U keys fanning outward
    translate([3, -34, 0]) rotate([0, 0, 12]) cap("1.5U_Normal");
    translate([-16, -40, 0]) rotate([0, 0, 27]) cap("Normal");
    translate([-33, -48, 0]) rotate([0, 0, 42]) cap("Normal");
}

// Left half (extends left of center) + right half (mirrored).
translate([-gap / 2, 0, 0]) hand();
translate([ gap / 2, 0, 0]) mirror([1, 0, 0]) hand();

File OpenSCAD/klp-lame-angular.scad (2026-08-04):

// =============================================================
// KLP Lamé Angular — low-profile faceted remix of KLP Lamé
// -------------------------------------------------------------
// Angular keycaps with flat, crisp trapezoid sides that keep the
// signature dished top of KLP Lamé (concave scoop rising toward
// all four edges, rolling off over the front/back walls), at a
// slightly reduced overall height. Stem and cavity dimensions are
// taken from the original KLP Lamé STLs, so switch fit is identical
// to the proven originals; where the inside is shaped for printing
// instead, it is only ever in the direction that adds clearance.
//
// Designed for FDM printing (tested target: Bambu Lab A1 mini,
// 0.4 mm nozzle) and resin printing.
//
// Original KLP Lamé by braindefender:
//   https://github.com/braindefender/KLP-Lame-Keycaps
// License: same as the original repository (see /LICENSE).
// =============================================================

/* [Main] */
// Switch stem type
stem_type = "choc"; // [choc, mx]
// Keycap footprint size
size_type = "choc"; // [choc, mx, mx_tight]
// Key width in units (1.5U is stretched horizontally, stem centered)
key_units = 1; // [1:0.25:2]
// Key depth in units (stretched front-to-back, stem centered)
key_units_y = 1; // [1:0.25:2]
// Top profile variant. normal = dished flat cap; tilted = the same cap
// tilted up toward the back for the rows above/below the home row.
variant = "normal"; // [normal, tilted]
// Homing feature on the touch surface
homing = "none"; // [none, bar, dots]

/* [Body] */
// Sidewall style — how the cap goes from its full-size bottom rim up
// to the touch surface. Drives how big the visible gap between caps is.
//   wide    : straight taper, classic sculpted look (biggest gap)
//   chiclet : near-vertical walls, large top, LAK/laptop-like (tightest)
//   skirt   : vertical skirt at the bottom, then taper above
side_style = "chiclet"; // [chiclet, wide, skirt]
// Height of the crown (top edge of the cap) above the bottom rim
crown_height = 5.0;
// wide: how much each side face leans in from bottom to top (per side)
top_inset = 2.0;
// chiclet: side inset per side (small = walls almost vertical)
chiclet_inset = 0.75;
// chiclet: rounding of the top perimeter edge (larger, softer bevel)
chiclet_edge_round = 1.3;
// skirt: height of the vertical full-size skirt at the bottom
skirt_height = 1.5;
// skirt: side inset per side above the skirt
skirt_inset = 1.5;
// Shape of the four vertical corners. "round" is a true radius, whose
// tangent runs ~90 deg where it meets a wall — printed on that wall it
// flares almost horizontally out of the first layers and curls into
// the nozzle. "chamfer" cuts the same corner at 45 deg, so nothing on
// the cap ever overhangs by more than 45 deg.
corner_style = "chamfer"; // [chamfer, round]
// Corner radius / chamfer of the bottom footprint (vertical corners)
corner_radius = 1.9;
// Corner radius of the top face (vertical corners)
top_corner_radius = 1.9;
// Rounding of the top perimeter edge (top face -> side wall)
top_edge_round = 1.0;
// Chamfer of the bottom perimeter edge (side wall -> rim). Zero by
// default: the chamfer only ever relieved elephant foot for a
// bottom-down print, and it is actively harmful for the tipped print
// the set is meant for — a 45 deg chamfer tipped ~45 deg turns into a
// dead-horizontal 8.8 mm2 shelf on the outside of the cap.
bottom_edge_round = 0;

/* [Top surface] */
// Depth of the dished scoop at the cap center, below the crown
dish_depth = 1.15;
// Radius of the spherical dish (smaller = deeper/rounder scoop)
dish_radius = 28;
// Tilt angle for tilted variants. Enough rake that the row above and
// below the home row meet the fingertip square-on rather than reading
// as a slightly canted flat cap. Every degree here also raises the
// cap's rear edge by cap_d * sin(tilt) — at 15 deg on an 18.5 mm cap
// the rear crown lands 4.8 mm above the front one.
tilt_angle = 15;
// Crown height at the front footprint edge for tilted variants. Setting
// this to crown_height makes the tilted cap's near edge meet the home
// row at the same height — a seamless bowl across the three rows.
tilt_front_height = 5.0;

/* [Shell] */
// How much the cavity flares out per side between the rim and the
// ceiling, i.e. how much thinner the wall is where it meets the roof.
//
// The cavity used to narrow going up, which left its walls leaning
// 30 deg in over the void — tipped for printing, an 80 deg overhang
// across 32 mm2, by a wide margin the worst surface on the cap. Flaring
// it the other way tips those same walls away from the void, so they
// print as self-supporting faces instead. It costs nothing in fit: the
// switch housing narrows as it rises, so a cavity that widens on the way
// up only ever gains clearance.
cavity_flare = 0.25;
// Wall the flare must leave where the cavity meets the roof. The flare
// is taken out of whatever the wall can spare above this and no more, so
// a footprint with a thin rim simply ends up with a straight cavity
// rather than a wall the nozzle cannot lay down.
wall_min = 0.6;

/* [Homing] */
// Raised bar: length
bar_length = 5.2;
// Raised bar: width
bar_width = 0.9;
// Raised bar / dots: height proud of the surface
homing_height = 0.3;
// Homing feature position, forward of center
homing_offset = 2.3;
// Dots: radius
dot_radius = 0.45;
// Dots: spacing from center
dot_spacing = 2.2;

/* [Hidden] */
$fa = 2;
$fs = 0.3;
eps = 0.01;

// ------------------------------------------------------------------
// Derived dimensions
// ------------------------------------------------------------------
// Footprints. The first two are measured from the original STLs; the
// third is those caps closed up onto the 19.05 mm pitch a Corne v4 Mini
// actually uses, which is where its half millimetre goes.
//   choc     : 17.5 x 16.5 on 18/17 mm pitch  (0.5 mm gap at the rim)
//   mx       : 18   x 18   on 19    mm pitch  (1.0 mm gap)
//   mx_tight : 18.5 x 18.5 on 19.05 mm pitch  (0.55 mm gap)
// Wider caps grow by whole pitches along X, so a 1.5U choc cap comes out
// 26.5 mm as in the original 1.5U models, and the stem stays centered.
base_w = size_type == "choc" ? 17.5 : size_type == "mx_tight" ? 18.5 : 18.0;
base_d = size_type == "choc" ? 16.5 : size_type == "mx_tight" ? 18.5 : 18.0;
pitch_x = size_type == "choc" ? 18.0 : size_type == "mx_tight" ? 19.05 : 19.0;
pitch_y = size_type == "choc" ? 17.0 : size_type == "mx_tight" ? 19.05 : 19.0;
cap_w = base_w + (key_units   - 1) * pitch_x;
cap_d = base_d + (key_units_y - 1) * pitch_y;

// The dish is stretched with the cap so bigger caps keep the same
// scoop character (matches the original 1.5U models).
dish_sx = cap_w / base_w;
dish_sy = cap_d / base_d;

// Cavity depth (bottom rim -> ceiling), from the originals:
//   choc stem: 2.05 mm, mx stem: 2.0 mm
cavity_depth = stem_type == "choc" ? 2.05 : 2.0;

is_tilted = variant == "tilted";

// Effective sidewall inset and top edge rounding for the chosen style
side_inset = side_style == "chiclet" ? chiclet_inset
           : side_style == "skirt"   ? skirt_inset
           :                           top_inset;
top_edge_r = side_style == "chiclet" ? chiclet_edge_round : top_edge_round;

// Top face: the same inset on all four sides. Standing the rear wall up
// on its own was tried as a print fix and dropped — it left the cap
// front/back asymmetric for a gain the tip angle gives for free.
top_w = cap_w - 2 * side_inset;
top_d = cap_d - 2 * side_inset;

// Wall at the rim. The cavity has to clear the same switch whatever the
// footprint, so mx_tight spends its extra 0.5 mm on the rim rather than
// on a wider cavity: 1.25 mm of wall leaves the same 16.0 mm mouth the
// 18 mm mx cap has, and the original 1.0 mm elsewhere.
wall_bottom = size_type == "mx_tight" ? 1.25 : 1.0;

// The outer wall leans in as it rises, so it eats into the wall by the
// time the cavity reaches its ceiling all on its own. Whatever is left
// above wall_min, up to cavity_flare, is what the cavity may flare by —
// which on the thin-rimmed footprints comes out at zero, leaving them a
// straight cavity instead of an unprintable wall.
outer_thin = side_inset * cavity_depth / (crown_height - top_edge_r);
flare = min(cavity_flare, max(0, wall_bottom - outer_thin - wall_min));
wall_top = wall_bottom - flare;

// Sagitta of a circle: rise of the arc at horizontal offset w from apex
function sag(r, w) = r - sqrt(r * r - w * w);

// Local top-surface height (z below the crown, negative) on the cap
// centerline at local y. Used to seat homing features.
function surf_z(y) = -(dish_depth - sag(dish_radius, y));
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

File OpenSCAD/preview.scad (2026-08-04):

// Preview: one column of the finished set (Corne v4 Mini, 19.05 mm
// pitch). The tilted rows meet the home row at the same height, then
// rake away from it — up at the back on the top row, up at the front on
// the bottom one, so the three rows read as one shallow bowl.
dir = "STL/MX Stem + MX Tight Size/";
p   = "MX_Stem_MX_Tight_Size_Angular_";
pitch = 19.05;
for (i=[-1:1]) {
  translate([i*pitch,  pitch, 0]) import(str(dir,p,"Normal_Tilted.stl"));
  translate([i*pitch,      0, 0]) import(str(dir,p, i==0 ? "Normal_Homing.stl" : "Normal.stl"));
  translate([i*pitch, -pitch, 0]) rotate([0,0,180]) import(str(dir,p,"Normal_Tilted.stl"));
}
translate([9.5, -40, 0]) import(str(dir,p,"1.5U_Normal.stl"));
translate([-pitch, -40, 0]) import(str(dir,p,"Normal.stl"));

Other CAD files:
OpenSCAD/STL/MX Stem + MX Tight Size/MX_Stem_MX_Tight_Size_Angular_Normal_Tilted.stl
OpenSCAD/STL/Choc Stem + MX Tight Size/Choc_Stem_MX_Tight_Size_Angular_Normal_Homing.stl
OpenSCAD/STL/MX Stem + MX Size/MX_Stem_MX_Size_Angular_Normal_Homing.stl
OpenSCAD/STL/Choc Stem + MX Tight Size/Choc_Stem_MX_Tight_Size_Angular_1.5U_Normal.stl
OpenSCAD/Plates/Plate_A1mini_Test_OneEach_RearSideDown.stl
OpenSCAD/STL/Choc Stem + Choc Size/Choc_Stem_Choc_Size_Angular_Normal_Homing.stl
OpenSCAD/STL/Choc Stem + MX Size/Choc_Stem_MX_Size_Angular_Normal_Homing.stl
OpenSCAD/STL/Choc Stem + MX Tight Size/Choc_Stem_MX_Tight_Size_Angular_Normal.stl
OpenSCAD/STL/MX Stem + Choc Size/MX_Stem_Choc_Size_Angular_Normal.stl
OpenSCAD/STL/MX Stem + Choc Size/MX_Stem_Choc_Size_Angular_Normal_Tilted.stl
OpenSCAD/STL/MX Stem + MX Size/MX_Stem_MX_Size_Angular_1.5U_Normal.stl
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

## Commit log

2026-07-22 feat: add OpenSCAD angular low-profile remix
    Parametric OpenSCAD remix of the Lamé profile with flat trapezoid
    sides and crisp edges, keeping the signature front/back-sloped dished
    top. Roughly 0.5 mm lower than the originals (Normal: ~4.4 -> 3.9 mm
    above the rim, Tilted: ~7.8 -> 6.9 mm) with stem and cavity dimensions
    measured from the original STLs for identical switch fit.
    - klp-lame-angular.scad: customizer-ready source (stem choc/mx,
    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
    [Choc_Stem_Choc_Size_Angular_Normal.stl, Choc_Stem_Choc_Size_Angular_Normal_Homing.stl, Choc_Stem_Choc_Size_Angular_Normal_Tilted.stl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]
2026-07-22 feat: rework angular profile to match reference sculpt
    Rebuilt the top-surface construction after side/iso reference review:
    - deep full-width cylindrical valley (R18) so the front/back lips
    rise above the side silhouette as winged tips, like the original
    Lamé profile, instead of a flat crown with shallow dishes
    - R1.4 fillet on all body edges via sphere-swept (minkowski) slabs,
    softer 2.2 mm footprint corners and 1.75 mm side draft
    - valley floor now 0.35 mm lower than the originals (MX Normal:
    3.5 -> 3.15 mm), tilted max height ~7.8 -> 6.6 mm
    - raised tilted crown front so tilted/saddle-tilted roofs stay
    printable (>0.9 mm) instead of cutting into the cavity
    - retuned thumb bev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
    [Choc_Stem_Choc_Size_Angular_Normal.stl, Choc_Stem_Choc_Size_Angular_Normal_Homing.stl, Choc_Stem_Choc_Size_Angular_Normal_Tilted.stl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]
2026-07-22 refactor: match reference — spherical dish on a flat rounded box
    Second pass after the side/top reference photos. The previous version
    read as a soft pillow with an over-strong saddle; this rebuilds the
    top from the original Lamé profile instead:
    - rounded-box body: genuinely flat trapezoid sides with a clear draft
    (top inset 2.0), only the perimeter edges softened (top edge R1.0),
    replacing the uniform R1.4 minkowski fillet
    - spherical dish reproducing the original scoop (concave, ~0.65 mm
    rise to all four edges) with a natural front/back roll-off, instead
    of the deep left-right valley
    - crown height 5.0 mm (below the ~5.6 mm original), dish floor ~3.9 mm
    - saddle reworked as a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
    [Choc_Stem_Choc_Size_Angular_Normal.stl, Choc_Stem_Choc_Size_Angular_Normal_Homing.stl, Choc_Stem_Choc_Size_Angular_Normal_Tilted.stl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]
2026-07-22 feat: add 1.5U support (key_units parameter)
    - key_units parameter stretches the cap along X (1.5U choc =
    26.5 x 16.5 mm, matching the original 1.5U models), stem stays
    centered and the spherical dish is stretched with the cap
    - build.sh now also renders 1.5U_Normal for every stem/size combo
    (32 STLs total)
    [Choc_Stem_Choc_Size_Angular_1.5U_Normal.stl, Choc_Stem_Choc_Size_Angular_Normal.stl, Choc_Stem_Choc_Size_Angular_Normal_Homing.stl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]
2026-07-22 fix: rework thumb as convex front roll-off
    Replace the crisp planar bevel with a convex cylindrical waterfall
    (R22, hinged 2 mm behind center): the back half keeps the spherical
    scoop and lip, the front rolls away smoothly toward a short front
    face, matching the reference and the original Lame thumb profile.
    [Choc_Stem_Choc_Size_Angular_1.5U_Normal.stl, Choc_Stem_Choc_Size_Angular_Normal.stl, Choc_Stem_Choc_Size_Angular_Normal_Homing.stl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]
2026-07-22 fix: thumb is now a pure convex dome waterfall
    Drop the dish entirely for the thumb: the top is a single convex
    ellipsoid surface (R30, stretched 1.5x sideways) cresting 2 mm
    behind center and 0.6 mm below the crown, waterfalling toward the
    front. One surface, no creases — a cleaner sculpt than the previous
    dish + roll-off combination.
    [Choc_Stem_Choc_Size_Angular_1.5U_Normal.stl, Choc_Stem_Choc_Size_Angular_Normal.stl, Choc_Stem_Choc_Size_Angular_Normal_Homing.stl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]
2026-07-22 feat: thumb waterfall now falls from a raised tilted-like back
    Crest moved to the back edge of the top face and the body raised
    0.8 mm at the back: the surface now descends monotonically from a
    high back (~5.6 mm) to a low front (~3.4 mm) over a single convex
    ellipsoid, reading like the tilted cap's high side flowing down.
    [Choc_Stem_Choc_Size_Angular_1.5U_Normal.stl, Choc_Stem_Choc_Size_Angular_Normal.stl, Choc_Stem_Choc_Size_Angular_Normal_Homing.stl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]
2026-07-22 add Corne v4 Mini keycap layout preview
    corne_layout.scad arranges the MX/Choc angular caps in the Corne v4
    Mini 3x5+3 split layout (finger column stagger, mirrored halves,
    3-key thumb fan) — keycaps only, for a visual mock-up.
    [corne_layout.scad]
2026-07-22 feat: add two 1.5U-deep thumb patterns (thumb_flat, thumb_slope)
    Deep (1.5U front-to-back) thumb caps stretched from the current thumb
    waterfall, via a new key_units_y depth-stretch parameter:
    - thumb_flat: flat back plateau at the crown, then the same 1U-style
    waterfall dropped only over the front ~11 mm (slope kept, rest flat)
    - thumb_slope: the whole top is one continuous slope from high back to
    low front, the drop distributed (prorated) over the full length
    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
    [Choc_Stem_Choc_Size_Angular_1.5U_Normal.stl, Choc_Stem_Choc_Size_Angular_1.5U_Thumb_Flat.stl, Choc_Stem_Choc_Size_Angular_1.5U_Thumb_Slope.stl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]
2026-07-22 refactor: drop thumb_flat (Pattern A), keep thumb_slope
    Consolidate on the distributed-slope 1.5U thumb. Remove the
    thumb_flat variant, its parameters (thumb_flat_run/radius) and
    keep-region module, the build target, and the generated
    1.5U_Thumb_Flat STLs. thumb_slope is now the single deep thumb.
    [Choc_Stem_Choc_Size_Angular_1.5U_Normal.stl, Choc_Stem_Choc_Size_Angular_1.5U_Thumb_Flat.stl, Choc_Stem_Choc_Size_Angular_1.5U_Thumb_Slope.stl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]
2026-07-23 feat: add A1 mini print plates for the Corne v4 Mini set
    Full both-hands set (36 caps: 20 Normal Tilted, 8 Normal, 2 Normal
    Homing, 6 Thumb; MX Stem + Choc Size) pre-arranged for the Bambu Lab
    A1 mini 180x180 bed, in two print orientations:
    - SideDown: caps laid on a (drafted) side wall so layer lines run
    across the top -> no tactile bumps on the touch surface
    - BottomDown: caps upright, bottom/stem toward the bed
    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
    [Plate_A1mini_BottomDown.stl, Plate_A1mini_SideDown.stl]
2026-07-23 fix: thumbs are 1.5U — use Thumb Slope on the print plates
    Swap the 6 thumbs on the A1 mini plates from 1U Thumb to the 1.5U
    Thumb Slope. Also give make_plate.py per-row heights so the deeper
    1.5U caps don't inflate every row. Both plates still fit the bed
    (SideDown ~159x84, BottomDown ~161x112). Docs/previews updated.
    [Plate_A1mini_BottomDown.stl, Plate_A1mini_SideDown.stl, pb.scad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]
2026-07-23 fix: thumb count — 1U x4 + 1.5U x2 (one 1.5U per hand)
    Correct the plate BOM: per hand two 1U thumbs + one 1.5U Thumb Slope,
    so 4x Thumb + 2x 1.5U_Thumb_Slope overall. Plates regenerated
    (BottomDown ~161x103), docs and previews updated.
    [Plate_A1mini_BottomDown.stl, Plate_A1mini_SideDown.stl]
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2026-07-25 fix: flip thumb test caps for stability
    [Plate_A1mini_Test_OneEach_MinContact.stl]
2026-07-25 fix: align test plate stem directions
    [Plate_A1mini_Test_OneEach_MinContact.stl]
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2026-07-26 fix: orient 1u caps top-down for printing
    [KLP_Lame_6Cap_A1mini_PLA_Quality.3mf]
2026-07-26 fix: place 1u caps on rear side face
    [KLP_Lame_6Cap_A1mini_PLA_Quality.3mf]
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2026-07-26 fix: lay homing key on side face
    [Plate_A1mini_Test_OneEach_RearSideDown.stl]
2026-07-26 feat: 18x18 mm footprint options — three sidewall styles
    For a 19 mm pitch the old 17.5 x 16.5 footprint leaves big, uneven
    gaps. Add a side_style parameter on the 18 x 18 (mx) footprint so the
    gap can be tuned, and set the mx pitch to a round 19.0 mm:
    - wide : current straight taper, top 14x14 (5.0 mm gap between tops)
    - chiclet : near-vertical walls, top 16.5x16.5, softer top edge round
    (2.5 mm gap) — the tight LAK/laptop-style grid
    - skirt : vertical full-size skirt for the first 1.5 mm, then taper
    to 15x15 (1 mm gap at the rim, 4 mm higher up)
    Top surface (spherical dish), stem and cavity are unchanged.
    [klp-lame-angular.scad]
2026-07-26 fix: chiclet tilt height and thumb waterfall fit
    chiclet's larger top face reaches further front/back, which broke two
    things at the 18 x 18 footprint:
    - tilted rose to 8.4 mm because the top face's rear edge sits further
    back; give chiclet its own lower tilt front (3.0) -> 7.1 mm tall
    with a 1.29 mm front roof
    - the thumb waterfall fell too far by the time it reached the front
    edge: 0.61 mm of roof on the 1U and an actual breach into the
    cavity on the 1.5U slope. Fit the dome's Y semi-axis analytically so
    the surface lands on thumb_front_height (3.3 mm, matching the
    approved 1U feel) at the front edge on any size or side style.
    Roof is now 1.7-1.9 mm on both.
    [klp-lame-angular.scad]
2026-07-26 refactor: chiclet 18x18 set — gentle tilt, thumb/saddle variants dropped
    Settle the redesign on the chiclet sidewall at the 18 x 18 footprint
    (19 mm pitch, 2.5 mm gap between tops) and make it the default.
    - tilt: 15 deg -> 8 deg with the front edge at crown_height, so a
    tilted cap's near edge meets the home row at the same height and the
    three rows read as one continuous bowl instead of a V step. Tilted
    is 7.2 mm tall with a 2.96 mm front roof.
    - drop the thumb, thumb_slope, saddle and saddle_tilted variants and
    all their parameters/modules; thumb positions use Normal and
    1.5U Normal. Variants are now normal / tilted (x homing, x 1.5U).
    - plates move to MX Stem + MX Size and th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
    [Choc_Stem_Choc_Size_Angular_1.5U_Normal.stl, Choc_Stem_Choc_Size_Angular_1.5U_Thumb_Slope.stl, Choc_Stem_Choc_Size_Angular_Normal.stl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]
2026-07-26 feat: single-plate Corne set with mirrored left/right print orientation
    Plate_A1mini_Corne36_LeftRight.stl prints the whole 36-cap set in one
    go, split into two blocks: the rear block is the left hand, laid on
    each cap's left side wall, and the front block is the right hand, laid
    on its right side wall. The caps are left-right symmetric, so the
    parts are identical and only the orientation differs — which puts the
    support scars and any elephant foot on mirrored walls so the built
    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
    [Choc_Stem_Choc_Size_Angular_1.5U_Normal.stl, Choc_Stem_Choc_Size_Angular_Normal.stl, Choc_Stem_Choc_Size_Angular_Normal_Homing.stl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]
2026-07-26 fix: seat tilted caps flat on the plate instead of on an edge
    The side-down plates tipped every cap by one shared SIDE_ROT_Y, which
    is only correct for the flat caps. A Normal cap's side wall leans 12.8
    deg from vertical; Normal Tilted's leans 7.8 deg because its top edge
    is raked. Tipped by 102.8 deg the tilted cap therefore balanced on a
    single edge with 0 mm^2 of real contact and the rest of the wall lifted
    off the bed, so the slicer filled the gap with support.
    side_tip_angle() now derives the rotation from each model's own wall
    normal (Normal 102.8 deg, Normal Tilted 97.8 deg), used by both the
    left/right hands plate and the SideDown plate. Normal Tilted now rests
    on 40.9 mm^2 of flat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
    [Plate_A1mini_Corne36_LeftRight.stl, Plate_A1mini_SideDown.stl]
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2026-07-26 fix: print tilted caps rear-wall-down — their side walls are warped
    A tilted cap's rake lifts the top edge while the bottom rim stays
    level, so the top and bottom edges of its left/right walls are skew
    lines and the ruled wall between them is a twisted surface: 0.19 mm of
    warp, roughly two layers, and the lean varies by 5.26 deg across the
    wall. Even at the correct per-model tip angle only 40.0 mm^2 of that
    64.7 mm^2 wall reaches the plate, so the slicer props up the rest —
    the unwanted support seen on the first print.
    Front and rear walls keep parallel top and bottom edges and stay
    planar (0.026 mm, same as a Normal cap). The rear wall is the taller
    and larger of the two, giving 77.6 m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
    [Plate_A1mini_Corne36_LeftRight.stl, Plate_A1mini_SideDown.stl]
2026-07-26 feat: align every cap's stem direction on the plates
    The three tip paths left stems pointing three different ways on the
    plate: 0 deg for right-side-down caps, 180 deg for left-side-down and
    90 deg for the rear-down tilted ones. Spin each cap in the build-plate
    plane so all 36 stems point at STEM_ANGLE_DEG (180). The spin is
    purely in-plane, so the chosen contact face and its area are
    unchanged, but support, seam and cooling now behave the same on every
    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
    [Plate_A1mini_Corne36_LeftRight.stl, Plate_A1mini_SideDown.stl]
2026-08-03 feat: vertical rear wall — removes the overhang that failed prints
    Design fix for the print failure instead of a slicer workaround. Laid
    on a side wall the cap's widest point is at mid-height, so every layer
    above it hung out past the one below: 511 mm^2 of outward-leaning
    outer surface spread over the full 16.6 mm of height. Those perimeters
    had nothing under them, curled up as they cooled, and the nozzle
    eventually struck the ridge.
    Giving the rear top edge zero inset (rear_inset = 0) makes the rear
    wall vertical. Tipped onto it, every outer surface of the cap is
    vertical or faces upward, so no perimeter ever hangs past its
    predecessor. Outer downward-facing area above the first millime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
    [Choc_Stem_Choc_Size_Angular_1.5U_Normal.stl, Choc_Stem_Choc_Size_Angular_Normal.stl, Choc_Stem_Choc_Size_Angular_Normal_Homing.stl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]
2026-08-04 revert asymmetry, print upright: rear wall was the wrong fix
    Two fair objections, both confirmed by measurement.
    The vertical rear wall does not remove the overhang. The top rounding
    and corner radii flare above the contact face regardless of what the
    wall below them does, so a rear-down cap still carries ~243 mm2 of
    outward-leaning outer surface (vs ~258 mm2 symmetric) and it is spread
    over the full 17.9 mm of height, not tucked near the bed. My earlier
    '54 mm2' came from a height histogram capped at 9 mm, which hid
    everything above it — the honest figure never supported the claim.
    And it cost the Normal cap its front/back symmetry for that ~6%. So
    rear_inset now defaults to negative, m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
    [Choc_Stem_Choc_Size_Angular_1.5U_Normal.stl, Choc_Stem_Choc_Size_Angular_Normal.stl, Choc_Stem_Choc_Size_Angular_Normal_Homing.stl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]
2026-08-04 fix: tip caps 70 deg instead of laying them flat on a wall
    The touch surface has to stay layer-line free, so upright is out and
    the cap must be printed on its side. But laying it flat on a wall is
    the worst version of that: the silhouette still has to grow from the
    small contact patch out to the cap's full width, and flat on a wall it
    does so inside the first millimetre or two. Measured typical (p90)
    outward growth per 0.2 mm layer is ~66 deg there — that is the
    perimeter that curled up and struck the nozzle.
    Tipping part-way spreads the same growth over much more height. Swept
    from upright to flat, the typical overhang is 88 deg upright, 55 deg
    at 45, bottoms out near 47 deg across 65-75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
    [Choc_Stem_Choc_Size_Angular_1.5U_Normal.stl, Choc_Stem_Choc_Size_Angular_Normal.stl, Choc_Stem_Choc_Size_Angular_Normal_Homing.stl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]
2026-08-04 fix: tip 45 deg and drop support entirely
    Support is off the table, so the question becomes which surfaces
    actually need it. Splitting the steep overhangs into the visible outer
    shell and the hidden interior changes the answer completely — the
    cavity and stem sit inside the switch, and the cavity ceiling bridges
    between its own walls instead of hanging free, so only the outer shell
    governs.
    Outer-shell area steeper than 45 deg: 17.2 mm2 at a 45 deg tip, 61.4
    at 60 and 70, 80.8 flat on a wall. At 45 deg the visible surface is
    essentially self-supporting and the plate needs no support at all.
    The earlier 70 deg pick came from a silhouette-growth metric that the
    stem boss dominated — it w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
    [Choc_Stem_Choc_Size_Angular_1.5U_Normal.stl, Choc_Stem_Choc_Size_Angular_Normal.stl, Choc_Stem_Choc_Size_Angular_Normal_Homing.stl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]
2026-08-04 fix: drop the bottom chamfer and tip 50 deg — outer shell now clean
    Asked whether 45 deg really removes the overhangs, the honest answer
    was no: the outer shell still had a dead-horizontal 8.8 mm2 face. It
    turned out to be bottom_edge_round, the 45 deg chamfer around the
    bottom rim — tipped 45 deg it lies exactly flat, so the chosen angle
    was the worst possible one for it. That chamfer only ever relieved
    elephant foot on a bottom-down print, which is not the orientation
    this set uses, so it now defaults to 0.
    With it gone, sweeping the tip angle again:
    45 deg -> worst 54 deg, 35.0 mm2 over 45
    50 deg -> worst 50 deg, 0.2 mm2 over 45
    90 deg -> worst 90 deg, 80.8 mm2 over 45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
    [Choc_Stem_Choc_Size_Angular_1.5U_Normal.stl, Choc_Stem_Choc_Size_Angular_Normal.stl, Choc_Stem_Choc_Size_Angular_Normal_Homing.stl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]
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
